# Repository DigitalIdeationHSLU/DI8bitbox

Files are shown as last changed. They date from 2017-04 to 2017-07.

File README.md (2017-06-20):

# DI 8bitbox

"DI 8bitbox" - Digital Ideation Musterplatine zum 140 jährigen Bestehen der HSLU

## What is inside this repository?

* PCB EagleCad Files + Gerber production Files
* Firmware (Arduino Code source)
* Shell script to zip Gerber Files
* CAM File for Itead Studio

## Assembly

### Bills of materials

You'll need following parts in order to finish your board.

* 2 x 100R 0805 SMD resistors
* 1 x 1k 0805 SMD resistor
* 1 x SOT23-3 NPN Transistor
* 2 x 1206 LEDs (preferably white, change resistor according to your colour)
* 1 x Atttiny 84 SMD Version
* 1 x Pogopin Sparkfun Connector ([Link](https://www.sparkfun.com/products/11591))
* 1 x optionally a tiny loudspeaker

You can find the exact details in this [BOM](https://github.com/DigitalIdeationHSLU/DI8bitbox/blob/master/documentation/Warenkorb_juin13_0443.xls) Excel sheet.

### Soldering

With little soldering skills, you should be able to finish the board. Please be careful when mounting the LEDs and the Attiny, since orientation is important. See mounting diagram:

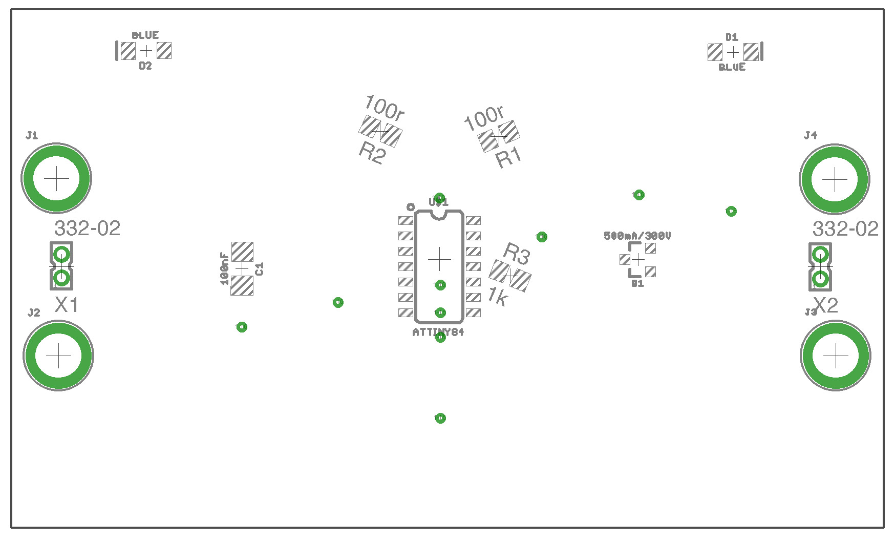
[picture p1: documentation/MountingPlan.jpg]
Mounting Plan


## Install

### Flashing Firmware

Attach the Pogo-pin programmer to an Arduino or another AVR ISP-capable programming device. For the wiring see this photo:

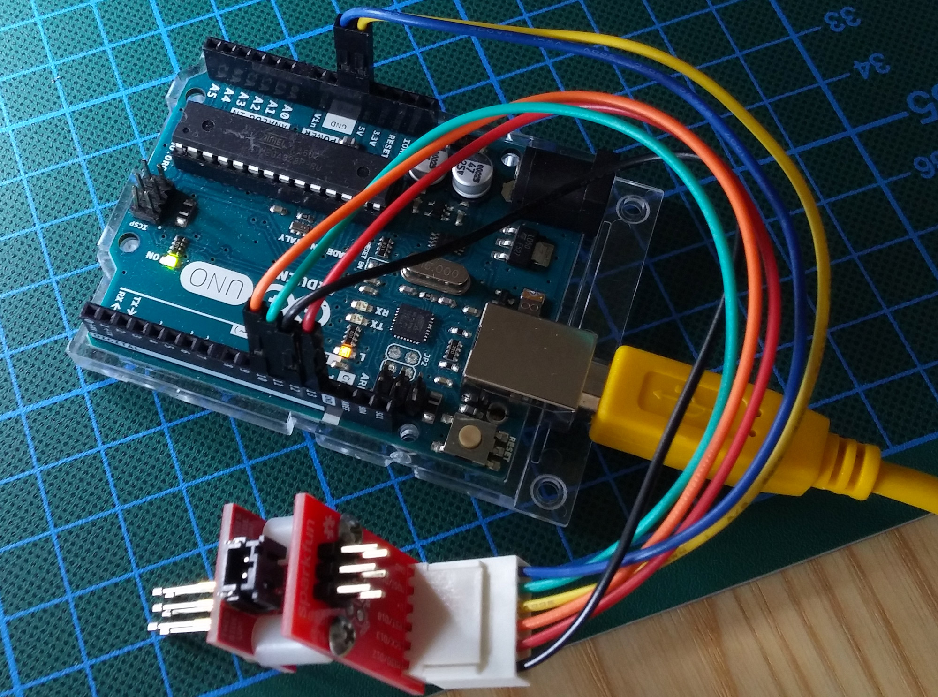
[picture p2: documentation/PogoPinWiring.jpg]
Pogo Pin Wiring


Once in place, prepare your Arduino by adding the Attiny to the list of boards. Here's a [HOWTO](http://highlowtech.org/?p=1695).

Make sure the Arduino settings are correct by selecting "Arduino as ISP", the right Board "Attiny84", the right clock frequency "1Mhz" and the right USB port.

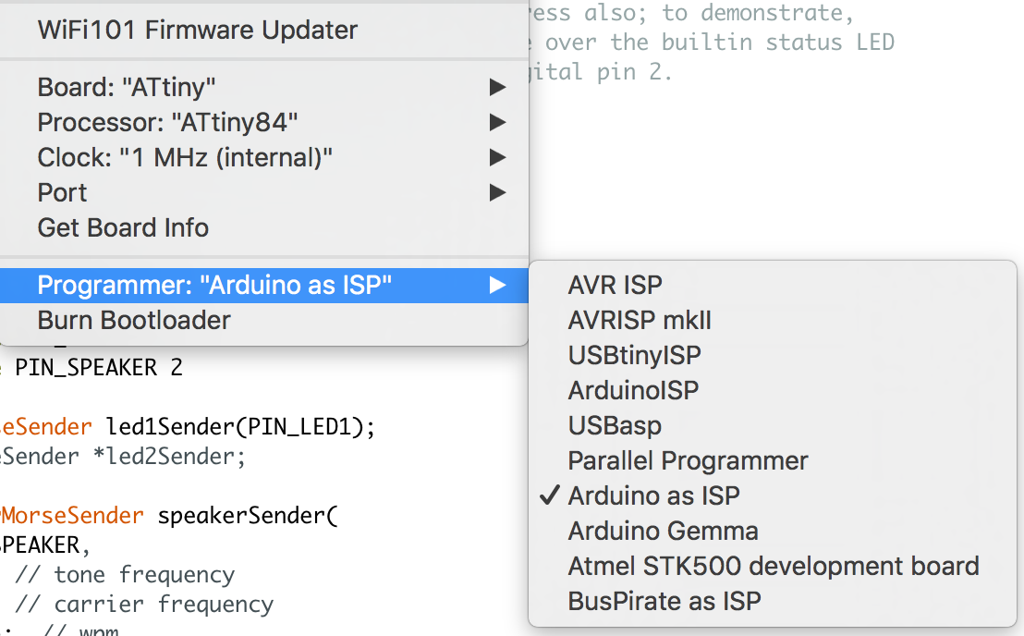
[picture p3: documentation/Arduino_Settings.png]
Arduino Settings


Press the Pogo pins gently onto the pads on the bottom side of the board. Again, orientation is important:

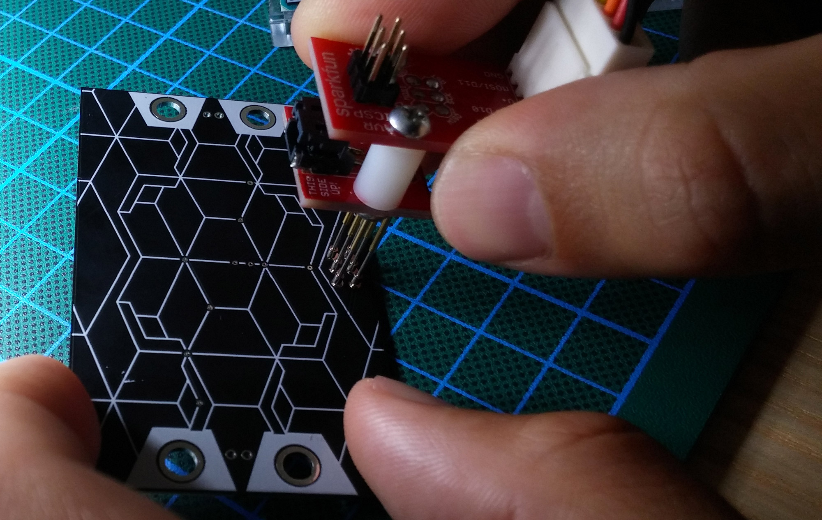
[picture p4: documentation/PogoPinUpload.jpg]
Pogo Pin Upload


Hit the programming button within your Arduino sketch. You should see a succesful File upload in the terminal screen of the Arduino IDE.

### Final preparation

Attach 3-5 Volts DC to the input pins where you'll find the battery icon. Make sure polarity is correct according to +/- signs. Solder the tiny loudspeaker on the other side of the board. You should hear sound coming out immediately.

## Run

Download either this [Android app](https://play.google.com/store/apps/details?id=org.jfedor.morsecode) for capturing sound or the [Morse Talk](https://play.google.com/store/apps/details?id=com.blueta.morsetransmitter&hl=fr) and hold it above one of the LEDs. You should be able to decrypt the message.

## Credits

* Created by Gordan Savičić & Michael Schürmann, Luzern 2017

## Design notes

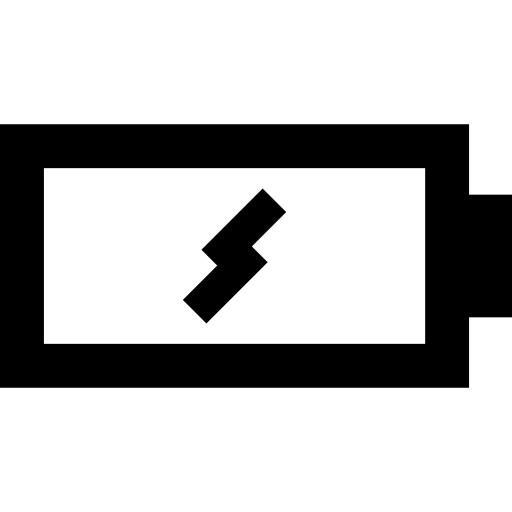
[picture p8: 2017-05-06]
graphics/assets/001-charging-battery.png

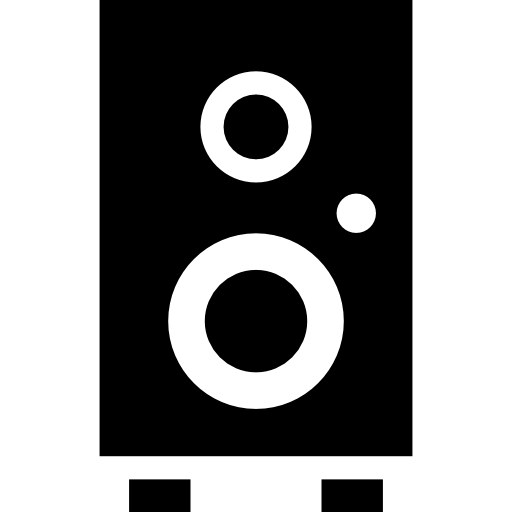
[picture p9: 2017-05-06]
graphics/assets/002-speaker.png

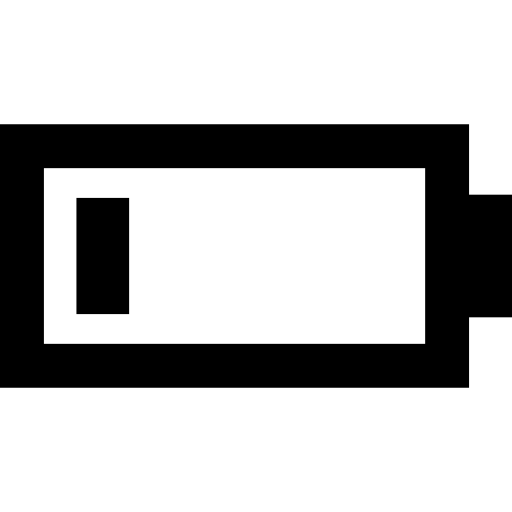
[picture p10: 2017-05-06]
graphics/assets/003-low-battery.png

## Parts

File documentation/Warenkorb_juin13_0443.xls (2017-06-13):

WARENKORB
Dies ist keine Rechnung
13-Jun-17 04:43:08
 | Mouser-Nr. | Herst.- Nr. | Hersteller | Kunden-Teilenr | Beschreibung | RoHS | Lebenszyklus | Stückzahl | Preis (CHF) | Gesamtpreis: (CHF)
1 | 603-RC0805FR-071KL | RC0805FR-071KL | Yageo |  | Dickfilmwiderstände - SMD 1K OHM 1% | RoHS-konform |  | 220 | 0.005 fr. | 1.10 fr.
2 | 603-RC0805FR-07100RL | RC0805FR-07100RL | Yageo |  | Dickfilmwiderstände - SMD 100 OHM 1% | RoHS-konform |  | 440 | 0.005 fr. | 2.20 fr.
3 | 696-SML-LX1206YW-TR | SML-LX1206YW-TR | Lumex |  | Standard-LEDs - SMD 3.2x1.6mm SMT LED Ylw 585nm Mlk Diff | RoHS-konform | Sonderbestellung ab Werk | 440 | 0.156 fr. | 68.64 fr.
4 | 556-ATTINY84A-SSU | ATTINY84A-SSU | Microchip |  | 8-Bit Mikrocontroller - MCU 20MHz Ind. Grade | RoHS-konform |  | 220 | 0.647 fr. | 142.34 fr.
5 | 80-C1206C104K5R | C1206C104K5RACTU | KEMET |  | Kondensator aus mehreren Keramikschichten MLCC - SMD/SMT 50volts 0.1uF X7R 10% | RoHS-konform |  | 220 | 0.028 fr. | 6.16 fr.
6 | 512-MMBT2222A | MMBT2222A | Fairchild Semiconductor |  | Bipolartransistoren - BJT SOT-23 NPN GEN PUR | RoHS-konform |  | 220 | 0.06 fr. | 13.20 fr.
Durch das Absenden Ihrer Bestellung erklären Sie sich mit diesen Geschäftsbedingungen einverstanden. (http://www.mouser.ch/saleterms) |  |  |  |  |  |  |  |  | Gesamtwarenkosten: | 233.64 fr.
Die Preise sind zum angezeigten Datum und zur Uhrzeit reflektiert. |  |  |  |  |  |  |  |  | Versandkosten: | 0.00 fr.

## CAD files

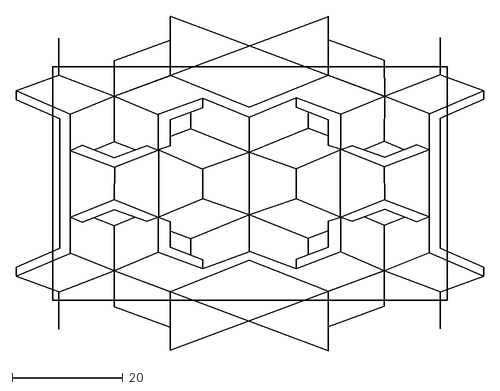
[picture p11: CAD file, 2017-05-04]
prod/Board.dxf
84.3 x 60.3

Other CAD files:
schematics/3d_preview/DI8bitbox.skp

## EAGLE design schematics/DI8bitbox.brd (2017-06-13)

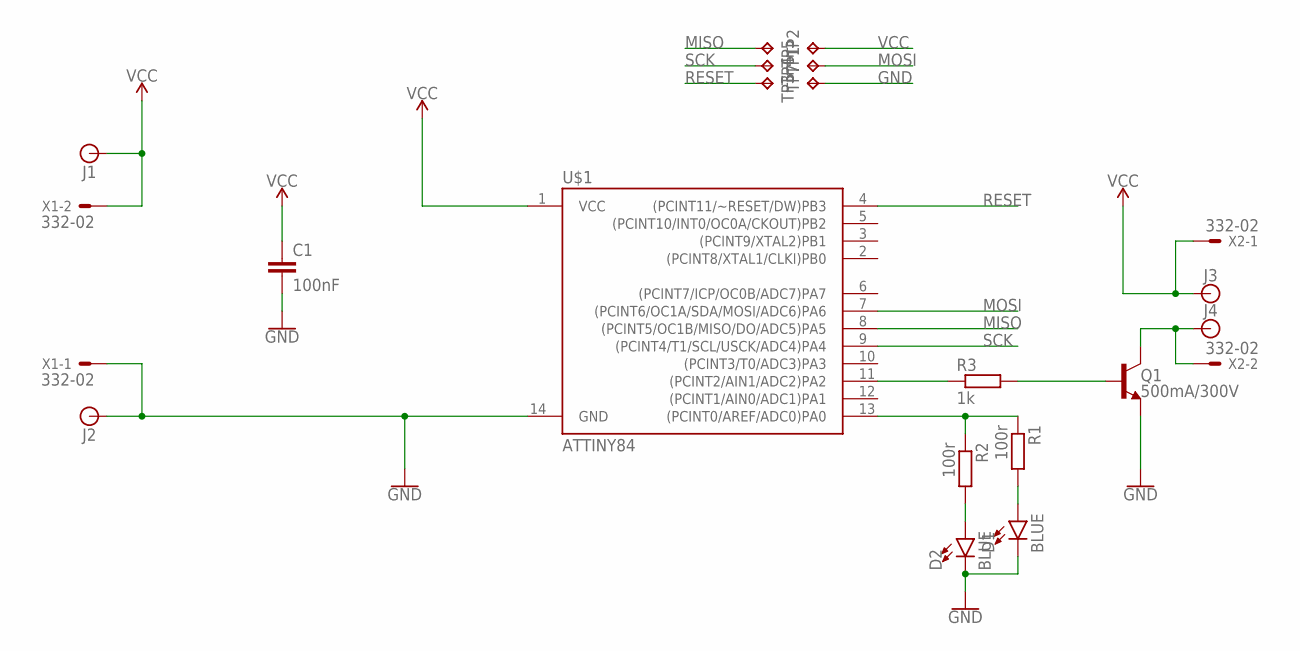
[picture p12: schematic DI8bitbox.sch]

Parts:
C1: 100nF; 1206
D1, D2: BLUE; LED-1206
J1, J2, J3, J4: BANANA_CONN
Q1: 500mA/300V; SOT23-3
R1, R2: 100r; M0805
R3: 1k; M0805
TP1, TP2, TP3, TP4, TP5, TP7: TPTP18R; TP18R
U$1: ATTINY84; SO14
X1, X2: 332-02

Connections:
GND: C1.2, D1.C, D2.C, J2.P$1, Q1.2 (E), TP7.TP, U$1.14 (GND), X1.1
MISO: TP5.TP, U$1.8 ((PCINT5/OC1B/MISO/DO/ADC5)PA5)
MOSI: TP1.TP, U$1.7 ((PCINT6/OC1A/SDA/MOSI/ADC6)PA6)
unnamed: R1.1, R2.1, U$1.13 ((PCINT0/AREF/ADC0)PA0)
unnamed: D2.A, R2.2
unnamed: D1.A, R1.2
unnamed: Q1.1 (B), R3.2
unnamed: R3.1, U$1.11 ((PCINT2/AIN1/ADC2)PA2)
RESET: TP3.TP, U$1.4 ((PCINT11/~RESET/DW)PB3)
SCK: TP4.TP, U$1.9 ((PCINT4/T1/SCL/USCK/ADC4)PA4)
SPK: J4.P$1, Q1.3 (C), X2.2
VCC: C1.1, J1.P$1, J3.P$1, TP2.TP, U$1.1 (VCC), X1.2, X2.1

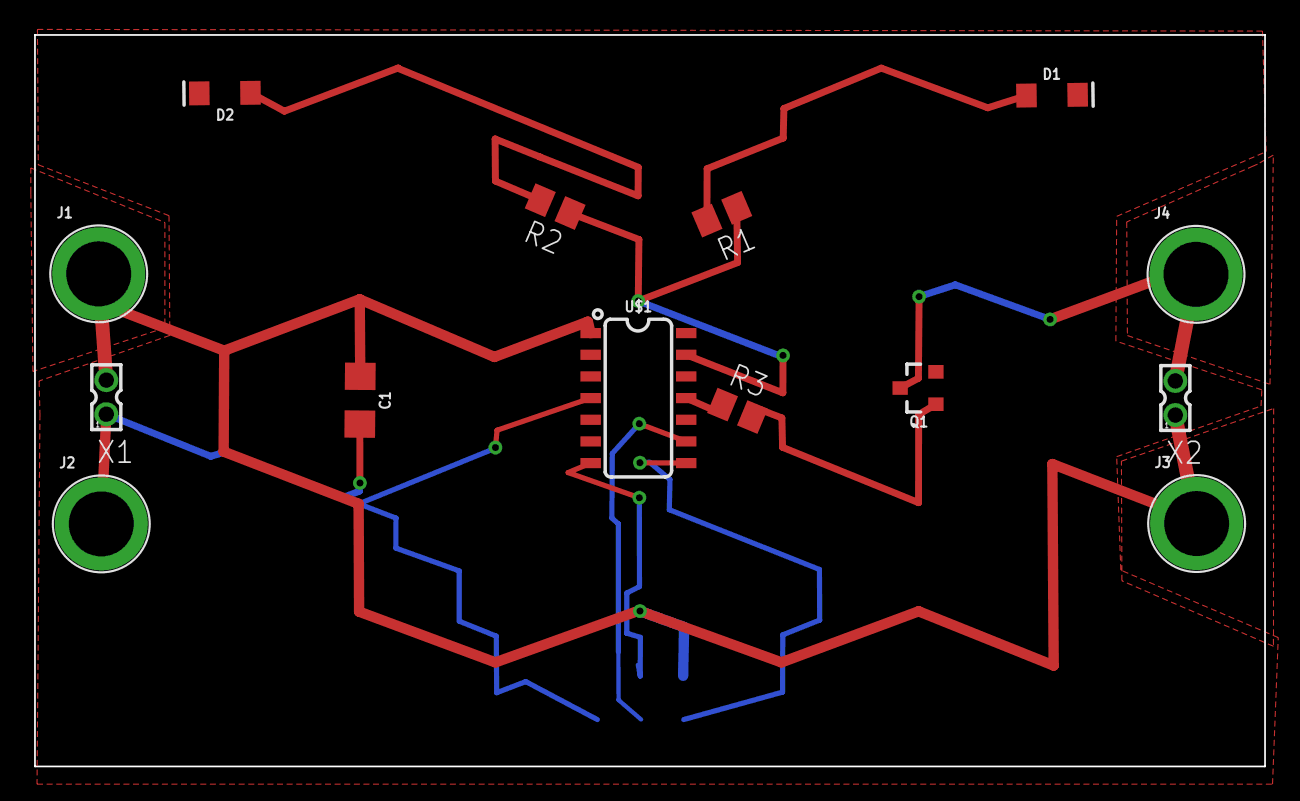
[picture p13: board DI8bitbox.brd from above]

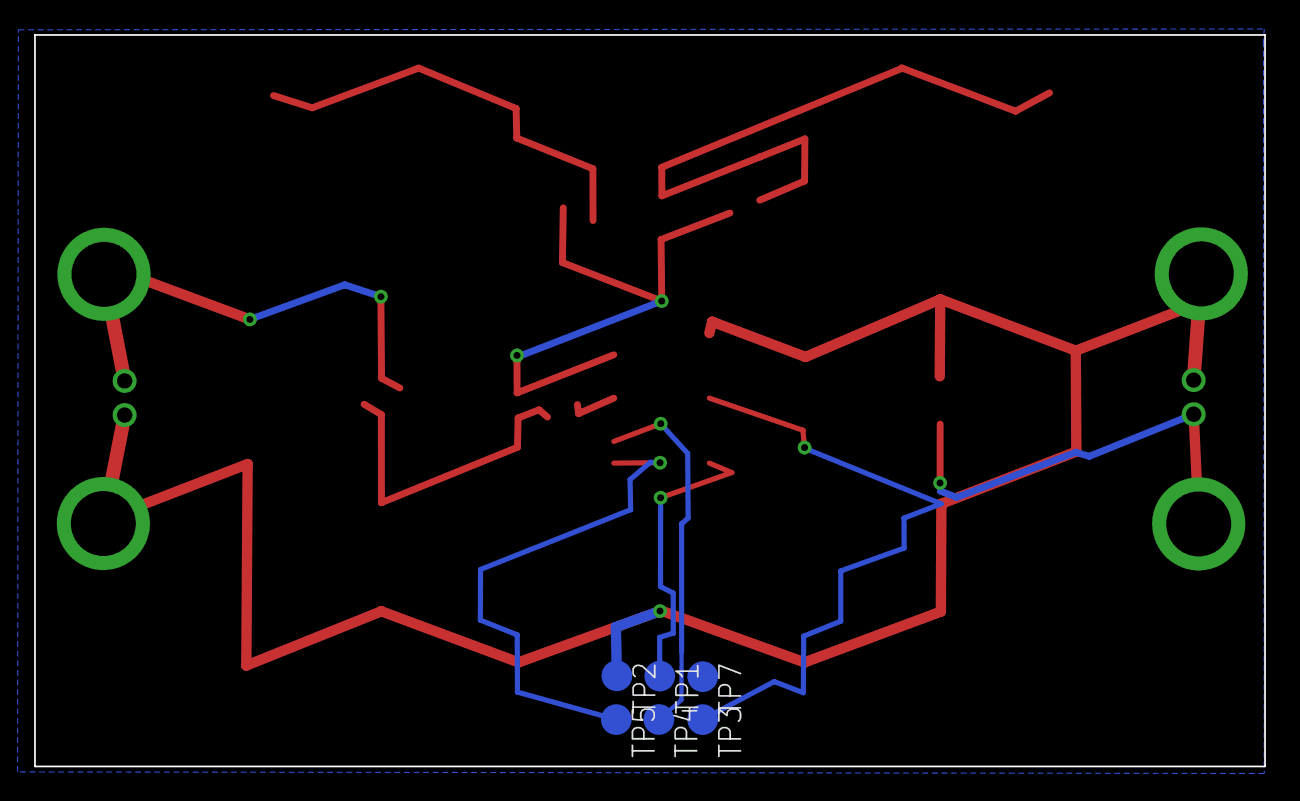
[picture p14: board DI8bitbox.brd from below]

Board: 2 copper layers, 72.1 x 42.9 mm, 20 parts (6 on the bottom side), 12 nets.

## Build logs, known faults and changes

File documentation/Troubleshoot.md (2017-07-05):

Ein paar Überlegungen die ich nachts über hatte:

* Überprüfe mit dem Multimeter (Verbindungstester) jeden Pin vom Pogo-Adapter bis hin zum Kabel das ins Arduino eingesteckt ist. Evtl. gibts irgendwo ein Übertragungsproblem.

* Vom Arduino Board entferne den Atmega Chip (mit einem flachen Schraubenzieher vorsichtig rausheben). Versuche nochmal das Programm hochzuladen (richtiger USB Port, Arduino as ISP, Attiny, 1mhz, etc. alle Einstellungen nochmals prüfen)

* öffne einen osx terminal dann probiere folgendes:

```
cd /Applications/Arduino.app/Contents/Java/hardware/tools/avr/bin/
```

das sollte klappen und schau mal ob avrdude dir einen output anzeigt

```
./avrdude -v
```

Mit avrdude lädt man die kompilierten hex Files vom Arduino auf den Chip. Das Arduino macht das automatisch. Mit avrdude können wir uns aber auch direkt in den Chip einloggen.

Pogo Pin draufhalten und folgendes im Terminal ausführen lassen:

```
./avrdude -c stk500v1 -P /dev/ttyUSB0 -p t84 -t
```

(Achtung: der Port muss übereinstimmen -> /dev/ttyUSB0. in deinem Fall könnte es auch der Port /dev/ttyACM0 sein bzw. /dev/ttyUSB1. bitte unbedingt überprüfen mit `ls /dev/tty` und dann TABULATOR Taste oder `ls /dev/ttyACM` und dann TABULATOR im Terminal). Der Terminal sollte dir anzeigen welcher Port existiert.

Kann sich avrdude mit dem Chip verbinden? Terminal mode sollte ungefähr so aussehen: http://www.nongnu.org/avrdude/user-manual/avrdude_9.html

Wenn ja, hurray!

Sobald du im Arduino auf Compile klickst wird ein Hex File erstellt. Das passiert aber in einem temp. Folder. Um das hex File zu bekommen, musst du oben im Menü Export
compiled binary anklicken. Wenn du jetzt in deinen Ordner schaust, solltest du ein hex file haben. z.B.

```
TestOutputs.ino.standard.hex
oder
SimpleMorse.ino.standard.hex
```

Jetzt können wir über avrdude direkt das hex File auf den Chip spielen. Dazu brauchen wir aber den absoluten Pfad vom hex File. Bei mir sieht der so aus (einfach vom Finder in den Terminal ziehen):

```
/Users/gordan.savicic/Documents/gordo/PROJEKTA/workshop/2016_2017_HSLU/PCB140JahreHSLU/hsluboard/firmware/SimpleMorse/SimpleMorse.ino.standard.hex
```

Im Terminal musst du nun aber im avrdude Folder sein. Also wieder:

```
cd /Applications/Arduino.app/Contents/Java/hardware/tools/avr/bin/
```

Jetzt kannst du es flashen. (Achtung: der Port muss übereinstimmen. /dev/ttyUSB0. in deinem Fall könnte es auch der Port /dev/ttyACM0 sein. bitte überprüfen mit `ls /dev/tty` und dann TABULATOR Taste oder `ls /dev/ttyACM` und dann TABULATOR im Terminal).

Copy/paste diese Zeile, achtung pfade ändern

```
stty -F /dev/ttyUSB0 hupcl && avrdude -c stk500v1 -b57600 -P /dev/ttyUSB0 -p t84 -u -U flash:w:/Users/gordan.savicic/Documents/gordo/PROJEKTA/workshop/2016_2017_HSLU/PCB140JahreHSLU/hsluboard/firmware/SimpleMorse/SimpleMorse.ino.standard.hex
```
Pogo-Pin draufhalten. Und Befehl ausführen (ENTER)

Soviel mal von meiner Seite!

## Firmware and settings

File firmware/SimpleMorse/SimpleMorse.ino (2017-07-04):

/**
   Send Morse while allowing other work to progress also; to demonstrate,
   send two Morse messages at the same time, one over the builtin status LED
   and the other over a speaker connected to digital pin 2.

   Speaker is connected to Pin 2
   LEDs are connected to Pin 0, Pin 1
*/

#include <morse.h>

#define PIN_LED 0
#define PIN_SPEAKER 2

LEDMorseSender ledSender(PIN_LED);
SpeakerMorseSender speakerSender(
  PIN_SPEAKER,
  880,  // tone frequency
  110,  // carrier frequency
  20.5);  // wpm

void setup()
{
  ledSender.setup();
  speakerSender.setup();

  ledSender.setMessage(String("// digital ideation "));
  speakerSender.setMessage(String("// digital ideation "));

  ledSender.startSending();
  speakerSender.startSending();

}

void loop()
{
  if (!ledSender.continueSending())  {
    ledSender.startSending();
  }
  if (!speakerSender.continueSending())  {
    speakerSender.startSending();
  }
}

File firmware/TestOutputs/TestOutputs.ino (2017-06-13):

/* Blink without Delay
    Example. test LEDs and speaker
 */

const int led1 =  1;      // the number of the LED pin
const int led2 =  0;
const int speaker = 2;

// Variables will change :
int ledState = LOW;             // ledState used to set the LED

// Generally, you should use "unsigned long" for variables that hold time
// The value will quickly become too large for an int to store
unsigned long previousMillis = 0;        // will store last time LED was updated

// constants won't change :
const long interval = 250;           // interval at which to blink (milliseconds)

void setup() {
  // set the digital pin as output:
  pinMode(led1, OUTPUT);
  pinMode(led2, OUTPUT);
  pinMode(speaker, OUTPUT);
}

void loop() {
  unsigned long currentMillis = millis();

  if (currentMillis - previousMillis >= interval) {
    // save the last time you blinked the LED
    previousMillis = currentMillis;

    // if the LED is off turn it on and vice-versa:
    if (ledState == LOW) {
      ledState = HIGH;
    } else {
      ledState = LOW;
    }

    // set LEDS
    digitalWrite(led1, ledState);
    digitalWrite(led2, ledState);
    digitalWrite(speaker, ledState);
  }
}

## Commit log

2017-04-12 added schematics and board design for morsecode with attiny84
    [MorseAttiny.brd, MorseAttiny.sch]
2017-04-29 New Version. Size 42.828 mm x 72.125 mm
    [MorseAttiny.brd]
2017-04-29 NEW NEW NEEEEEEEEEEW :)
    [MorseAttiny.brd]
2017-04-29 this is it! only bitmap left..
    [MorseAttiny.brd]
2017-05-01 restored deleted brd files
    [MorseAttiny.brd]
2017-05-04 inserted silkscreen layer from Silkscreen.ai into eagle brd file + added screenshots for documentation
    [Board.dxf, MorseAttiny.brd]
2017-05-05 cropped silkscreen mask
2017-05-05 Major changes in Illustrator design and first silkscreen experiments
    [MorseAttiny.brd, MorseAttiny.sch]
2017-05-06 changed pads to polygon areas, added eagle up renderings, major re-design
    [MorseAttiny.brd, MorseAttiny.sch]
2017-05-06 minor cleanups, first gerber files
    [MorseAttiny.GBL, MorseAttiny.GBO, MorseAttiny.GBP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]
2017-05-06 Ordered at Itead - rev.a finished
    [DI8bitbox.GBL, DI8bitbox.GBO, DI8bitbox.GBP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]
2017-05-08 added R3 to transistor base after itead prod
    [DI8bitbox.skp]
2017-05-08 added gerber files with R3
    [DI8bitbox.brd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]
2017-06-13 ordered rev.b at safepcb and mouser BOM updated
    [DI8bitbox.GBL, DI8bitbox.GBO, DI8bitbox.GBP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]
2017-06-21 removed ledpin2 from SimpleMorse

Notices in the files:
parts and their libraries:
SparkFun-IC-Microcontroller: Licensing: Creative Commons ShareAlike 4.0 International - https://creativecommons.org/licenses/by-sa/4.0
